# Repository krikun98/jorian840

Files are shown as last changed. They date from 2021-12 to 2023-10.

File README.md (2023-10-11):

# Jorian 840

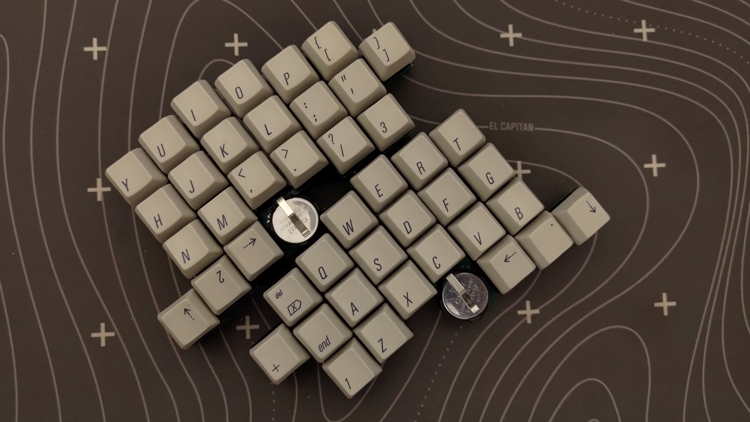
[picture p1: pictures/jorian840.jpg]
Jorian840 0.2 (https://youtu.be/hZC1p5ErBT8 "Jorian840 0.2")


44-key wireless split keyboard in a 100x100 mm PCB.

Two main versions are available with plenty of supported switches.

Plates and bottoms are to be cut from metal, acryllic or dual-layered plastic.

## Disclaimer

This is a modified version of Joric's Jorian.

The keyboard layout was derived from the [Jian layout](http://www.keyboard-layout-editor.com/#/gists/4b6c2af67148f58ddd6c6b2976c4370f) (just visually, there was no actual copying involved).
Please buy the Jian from its author, [/u/KgOfHedgehogs](http://reddit.com/u/KgOfHedgehogs) at [the official store](https://killswit.ch)

## Features

* Wireless via Holyiot 18010 modules
* Fully-featured ZMK split
* Uses either 233350 310 mAh, LIR2032 40 mAh or CR2032 220 mAh (non-rechargeable) batteries
* Charger on/off switch (for non-rechargeable batteries)
* Proper case support
* Adjustable pinky stagger in the solder version
* Can be built with 7 or 8 mm. standoffs even with the rechargeable battery under the PCB

## Download

You can download Gerber files and firmware in the [releases section](https://github.com/krikun98/jorian840/releases).
More images are also in Actions builds.

## Instructions

Please refer to the public [Jorian wiki](https://github.com/krikun98/jorian840/wiki).

For building the artifacts locally you need Docker. 
Just run the `build.sh` script.

However, everything is built in Actions. 
Check the Actions tab or releases for files not linked here.

### Firmware

The [bootloader](../../releases/latest/download/bootloader.hex) is available in the Releases tab.
Please refer to the [nrfmicro wiki](https://github.com/joric/nrfmicro/wiki/bootloader) for the flashing instructions.

[Default firmware](../../releases/latest/download/firmware.zip) files are also there, and you can use the [Jorian840](https://github.com/krikun98/zmk-config/tree/jorian840) `zmk-config` branch for customisation.

## Links

### Version 0.2

MX Hotswap 

[IBOM](https://htmlpreview.github.io/?https://github.com/krikun98/jorian840/blob/holyiot/pcb/hotswap/bom/ibom.html)

[gerbers](../../releases/latest/download/pcb_hotswap_gerbers.zip)

front|back
--|--
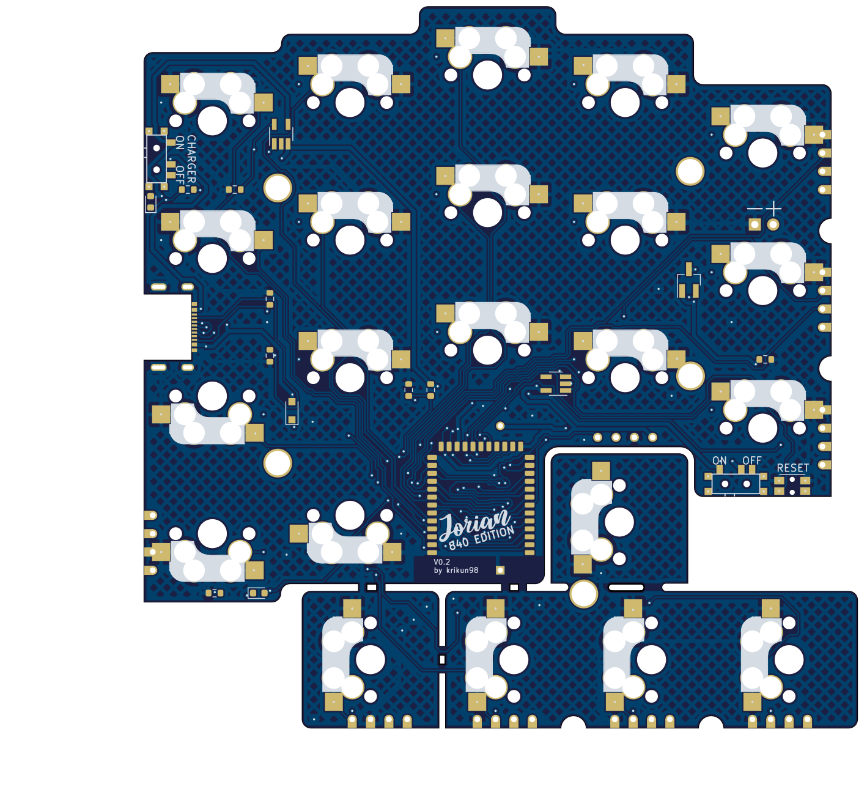
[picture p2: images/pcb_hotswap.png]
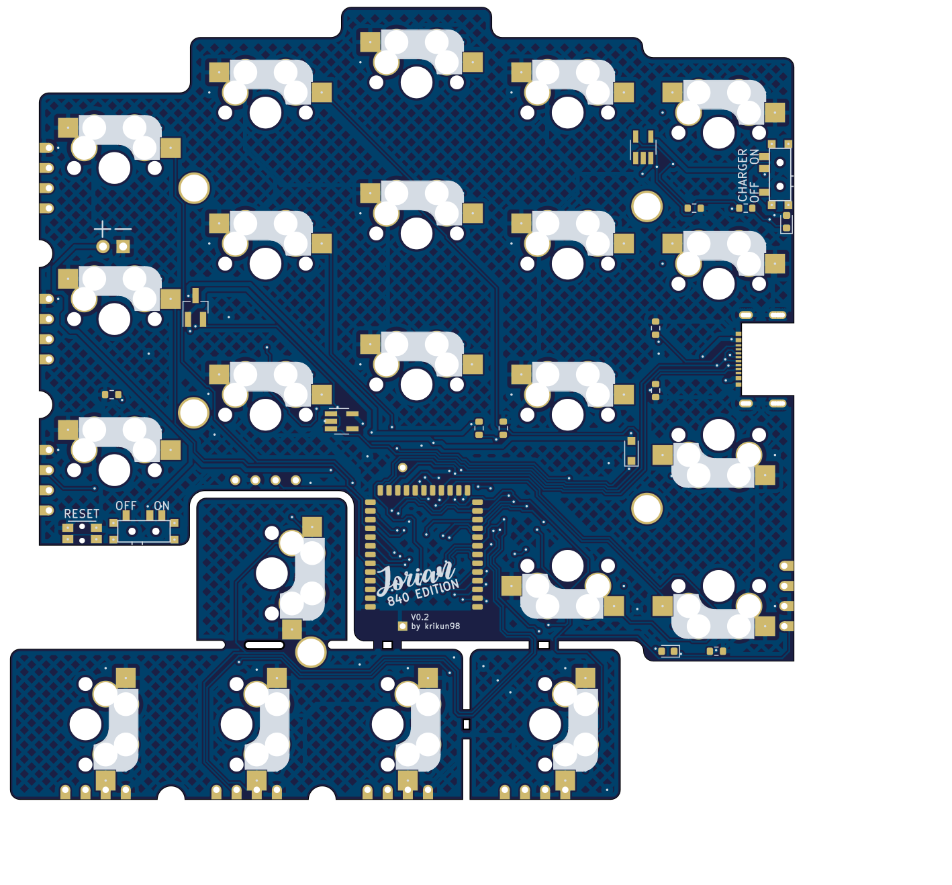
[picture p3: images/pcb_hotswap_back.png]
back
|

Solder (MX/Alps/Omron B3G-S)

[IBOM](https://htmlpreview.github.io/?https://github.com/krikun98/jorian840/blob/holyiot/pcb/solder/bom/ibom.html)

[gerbers](../../releases/latest/download/pcb_solder_gerbers.zip)

front|back
--|--
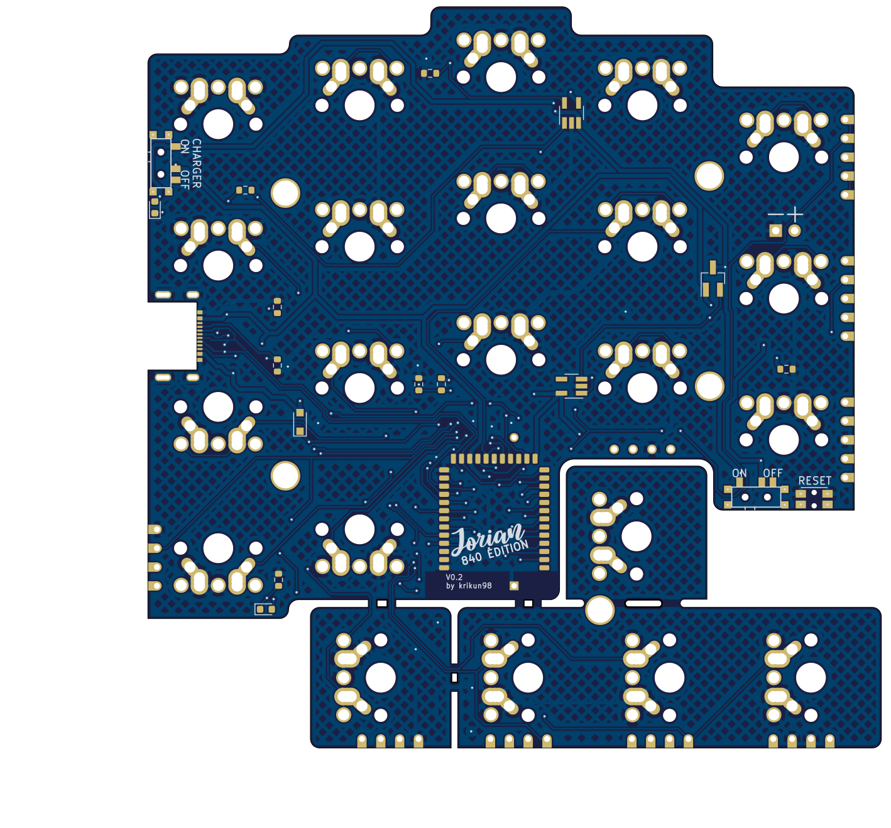
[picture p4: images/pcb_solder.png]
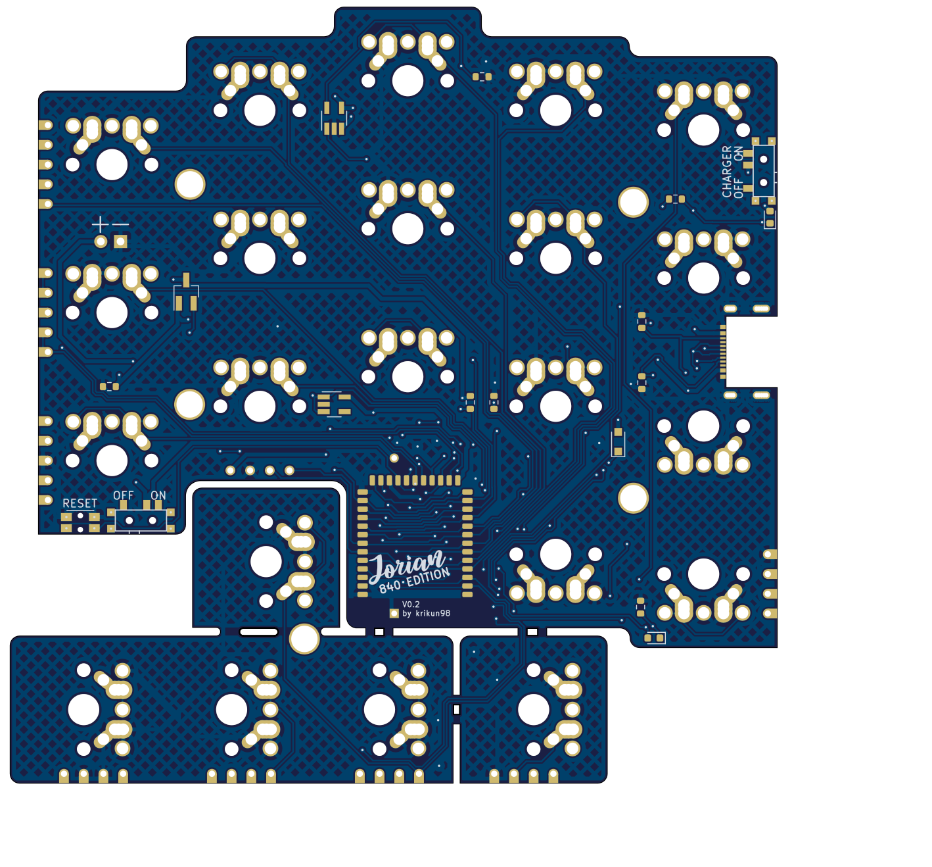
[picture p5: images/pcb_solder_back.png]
back
|

[Case files](../../releases/latest/download/case_files.zip) for all variations.

All the case files have the switch holes adjusted for laser cutting plastic (0.25 mm. smaller in both dimensions).
If your laser cutter has different tolerances - adjust them and re-run the build script.

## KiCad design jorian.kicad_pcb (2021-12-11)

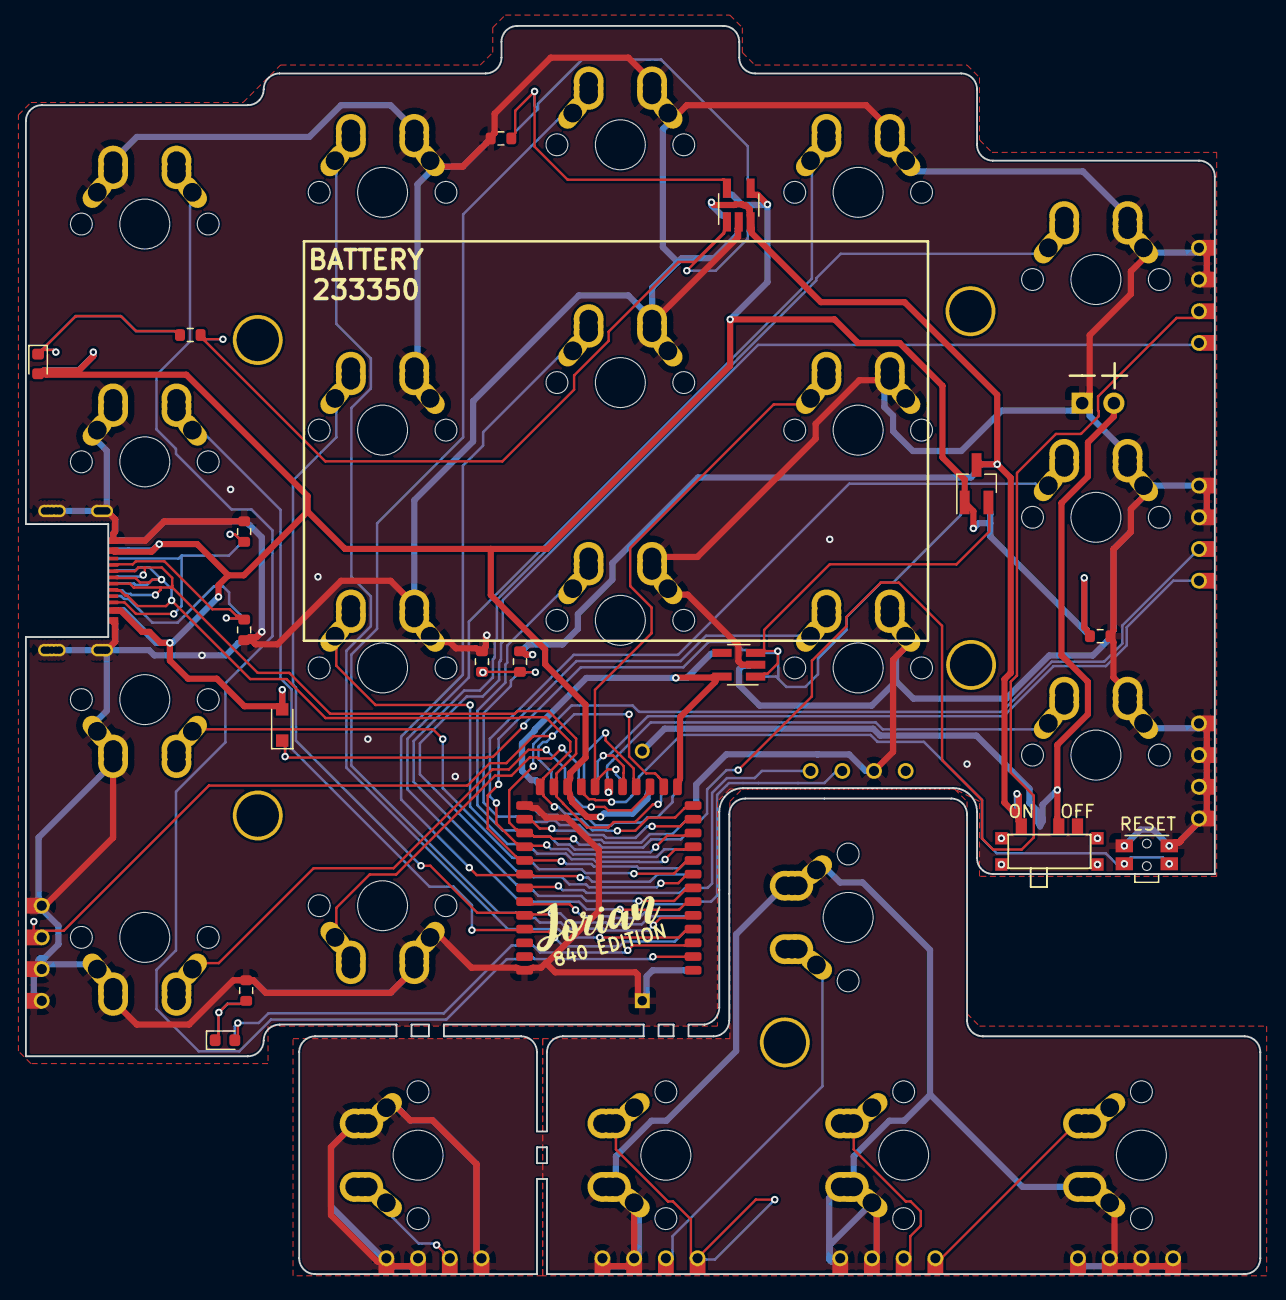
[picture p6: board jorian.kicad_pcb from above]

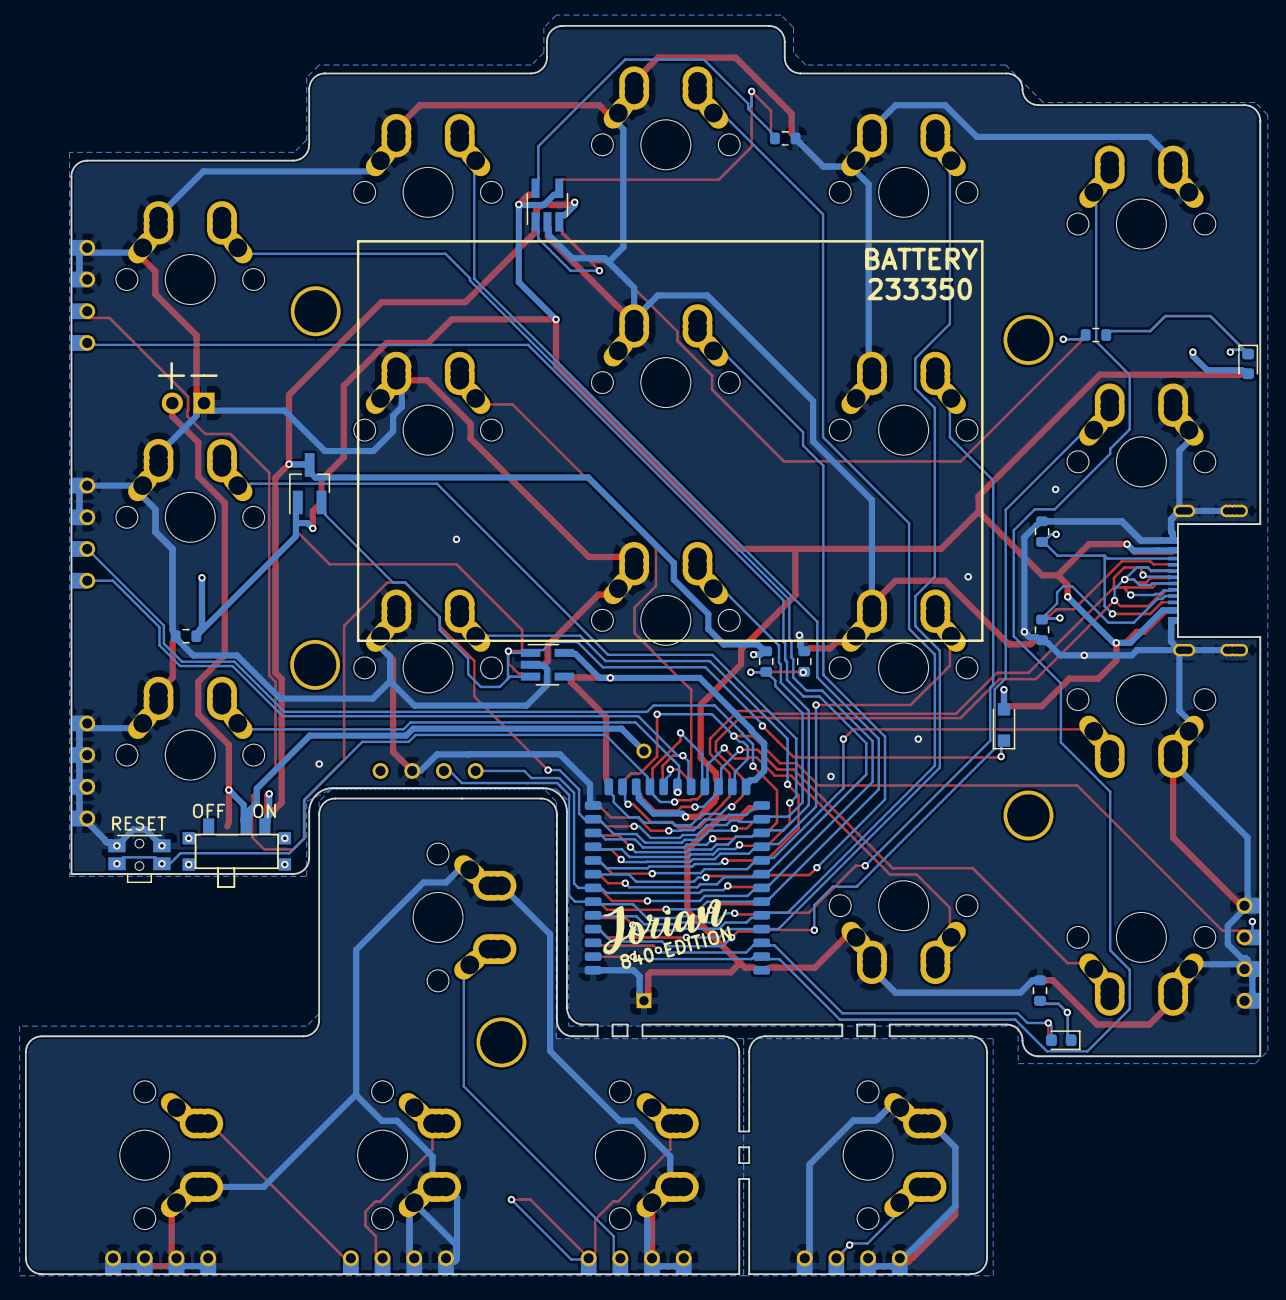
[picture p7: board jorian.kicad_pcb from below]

Board: 2 copper layers, 98.9 x 100.0 mm, 58 parts (5 on the bottom side), 48 nets.

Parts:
BT1: Battery Holder; cr2032_bs-7
D1: RED; LED_0603_1608Metric_REV
D2: 1N5819; D_SOD-323_HandSoldering_REV
D3: BLUE; LED_0603_1608Metric_REV
E5, E10, E15, E18: left; edge_conn
E16, E19, E20, E21: right; edge_conn
G1, G2: Logo_Open_Hardware_Small; jorian_logo
HM1, HM2, HM3, HM4, HM5: CaseHole; M2-MountingHole-Standoff
J1: USB-C Conn; USB-C_C168688_REV
J2: Ex_Bat; Battery_TH
JP16: SWD_conn; connector_swd
Q1: AO3407; SOT-23_Handsoldering_REV
R1, R2: 5.1K; R_0603_1608Metric_REV
R3, R8: 1K; R_0603_1608Metric_REV
R4: RPROG; R_0603_1608Metric_REV
R5: 820K; R_0603_1608Metric_REV
R6: 2M; R_0603_1608Metric_REV
R7: 100K; R_0603_1608Metric_REV
RSW1: SW_PUSH; SW_SPST_EVQP7C_REV
SW1, SW2, SW3, SW4, SW5, SW6, SW7, SW8, SW9, SW10, SW11, SW12, SW13, SW14, SW15, SW16, SW17, SW18, SW19, SW20, SW21, SW22: SW_PUSH; MX-Alps-1U-REV
SW23: SW_SPDT; SW_SPDT+H-MSK12C01_hor(7pin_SMD)_REV
U1: Holyiot-18010; Holyiot-18010-nRF52840-REV
U2: TP4054; SOT-23-5_HandSoldering_REV
U3: XC6220B331MR-G; SOT-23-5_HandSoldering_REV

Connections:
BATTERY_PIN: R5.2, R6.1, U1.12 (P0.04/AIN2)
BLUE_LED: D3.2 (A), U1.3 (P1.10)
CC1: J1.A5 (CC1), R2.1
CC2: J1.B5 (CC2), R1.1
DATA+: J1.A6 (D+), J1.B6 (D+), U1.24 (USB_D+)
DATA-: J1.A7 (D-), J1.B7 (D-), U1.23 (USB_D-)
GND: BT1.2 (-), E5.1, E5.2, E10.1, E10.2, E15.1, E15.2, E15.3, E15.4, E16.1, E16.3, E16.4, J1.A1 (GND), J1.S1 (SHIELD), J2.1, JP16.2, R1.2, R2.2, R4.2, R6.2, R7.2, R8.2, RSW1.2, SW1.1, SW2.2, SW3.2, SW4.2, SW5.2, SW6.1, SW7.2, SW8.2, SW9.2, SW10.2, SW11.2, SW12.2, SW13.2, SW14.2, SW15.2, SW16.2, SW17.1, U1.25 (GND), U1.37 (GND), U2.2 (VSS), U3.2 (GND)
GND_A: E18.1, E18.3, E18.4, SW18.2
GND_B: E19.1, E19.2, E20.1, E20.2, E21.1, E21.2, E21.3, E21.4, SW19.1, SW20.1, SW21.1, SW22.2
unnamed: D1.1 (K), R3.1
unnamed: D2.1 (K), Q1.2 (S), U3.1 (VIN), U3.3 (EN)
unnamed: D3.1 (K), R8.1
unnamed: R3.2, U2.1 (STAT)
unnamed: R4.1, U2.5 (PROG)
R1C1: E5.4, U1.8 (P0.28/AIN4)
R1C1B: E19.4, SW19.2
R1C2: SW5.1, U1.7 (P0.02/AIN0)
R1C3: SW4.1, U1.6 (P0.03/AIN1)
R1C4: SW3.1, U1.5 (P1.15)
R1C5: SW2.1, U1.4 (P1.13)
R1C6: SW1.2, U1.2 (P1.11)
R2C0: E5.3, U1.26 (P0.22)
R2C0B: E19.3, SW22.1
R2C1: E10.3, U1.27 (P1.00)
R2C1B: E20.3, SW20.2
R2C2: SW10.1, U1.28 (P1.03)
R2C3: SW9.1, U1.20 (P0.19)
R2C4: SW8.1, U1.30 (P1.02)
R2C5: SW7.1, U1.33 (P1.04)
R2C6: SW6.2, U1.34 (P1.06)
R3C1: E10.4, U1.18 (P0.23)
R3C1B: E20.4, SW21.2
R3C2: SW15.1, U1.19 (P0.21)
R3C3: SW14.1, U1.29 (P1.01)
R3C4: SW13.1, U1.11 (P0.31/AIN7)
R3C5: SW12.1, U1.10 (P0.30/AIN6)
R3C6: SW11.1, U1.9 (P0.29/AIN5)
R4C5: SW17.2, U1.17 (P0.12)
R4C6: SW16.1, U1.16 (P1.09)
R4C7: E16.2, U1.15 (P0.07)
R4C7A: E18.2, SW18.1
SWC: JP16.4, U1.31 (SWDCLK)
SWD: JP16.3, U1.32 (SWDIO)
VBAT: BT1.1 (+), J2.2, SW23.2 (B)
VBAT2: Q1.3 (D), R5.1, SW23.1 (A), U2.3 (VBAT)
VBUS: D1.2 (A), D2.2 (A), J1.A4 (VBUS), Q1.1 (G), R7.1, U1.22 (VBUS), U2.4 (VDD)
nRF_VDD: U1.14 (VDD), U3.5 (VOUT)
reset: RSW1.1, U1.21 (P0.18/RESET)

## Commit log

2021-12-11 Ready for 0.15 (6 mil) tolerances
    [jorian.kicad_pcb]
2021-12-11 Hatch pattern, antenna keepout
2021-12-12 Fixed power switch footprint
2022-01-07 Jorian840 0.1
    [corian_bottom.kicad_pcb, corian_plate.kicad_pcb, jorian.kicad_sch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]
2022-01-07 Generate images, DXF files and gerbers via Actions (#1)
    * Workflow draft
    * Separate workflows further
    * Forgot to save
    * Execution permissions
    * Typo
    * Docker permission fix
    * Order fix
    * Artifacts
    * Tabs
    * Removed variable
    * Readme updates from CI
    * JQ magic
    * Proper magic
    * Proper magic fix
    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
2022-01-07 Hole note
2022-01-08 Proper library management
    [jorian.kicad_sch]
2022-01-08 Battery capacity fix
2022-01-11 Moved traces away from switches that would be cut down
2022-01-11 Updated case hole footprints
    [corian_bottom.kicad_pcb, corian_plate.kicad_pcb, jorian_bottom.kicad_pcb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]
2022-01-13 Schematic ground fix
    [jorian.kicad_sch]
